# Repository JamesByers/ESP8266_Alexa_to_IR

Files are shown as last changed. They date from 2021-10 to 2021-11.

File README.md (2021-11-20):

# ESP8266 Alexa to IR controller
This repository demonstrates how to use an ESP8266 microcontroller to recieve Alexa commands and transmit corresponding IR commands. Specifically it demonstrates controlling a radiant heater that has no documentation of the IR signals sent. The code and technique can be leveraged for any IR device you want to control.

This repository assumes you know how to use the Arduino IDE and program an Arduino.  I used a [NodeMCU 1.0 ESP8266 development board](https://www.amazon.com/HiLetgo-Internet-Development-Wireless-Micropython/dp/B010O1G1ES) for this project. However this code can be used with other ESP8266 boards such as the [Adafruit HUZZAH ESP8266 Breakout](https://www.adafruit.com/product/2471) or [SparkFun ESP8266 Thing](https://www.sparkfun.com/products/13231).

##### The project described here controls a radiant heater which comes with an IR remote. This repository contains two code sections
1. [alexa_ir_controller](/alexa_ir_controller) (transmitter) - Circuit and code to use an ESP8266 to recieve Alexa commands and then issue the corresponding IR commands through an IR LED
2. [ir_receiver](/ir_receiver) - Code to detect the IR command signals sent from an IR remote using a IR reciever part

##### See the controller in use:

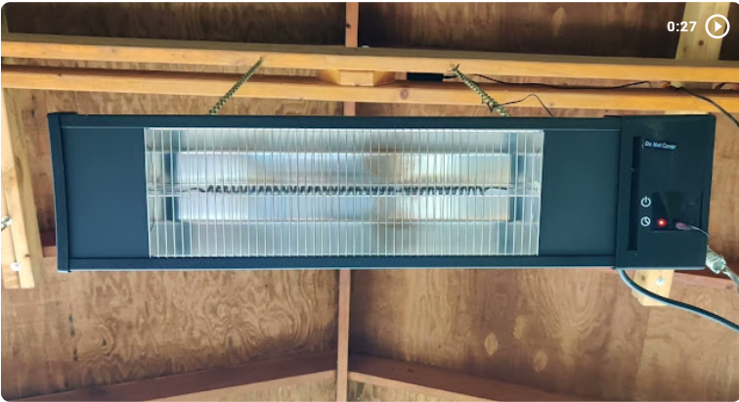
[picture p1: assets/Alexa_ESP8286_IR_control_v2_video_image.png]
The Alexa ESP8266 IR controller in action (27 sec) (https://photos.app.goo.gl/GmGifkKtMW2HBMPd7 "The Alexa ESP8266 IR controller in action (27 sec)")


##### Image of the completed controller

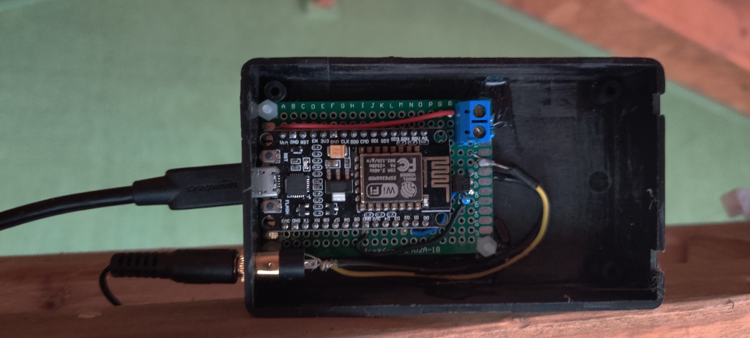
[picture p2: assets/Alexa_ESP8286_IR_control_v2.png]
Completed Alexa ESP8266 IR controller

Yeah, I know that looks like a cold solder joint but it is working reliably so I am leaving it as is.

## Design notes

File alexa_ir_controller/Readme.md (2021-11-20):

# ESP8266 Alexa to IR controller (transmitter)
This section of the repository demonstrates how to use an ESP8266 to recieve Alexa commands and transmit corresponding IR commands. Specifically it demonstrates controlling a radiant heater that has no documentation of the IR signals.  The NodeMCU Arduino code is available in the [code/alexa_ir_heater_controller](./code/alexa_ir_heater_controller/) folder.

### The IR codes
I obtained the IR codes by pushing each button on the remote and capturing it with the IR reciever set-up described in the [ir_receiver](../ir_receiver/) folder of this repository. The codes I captured can be seen in the [heater_remote_IR_codes](../ir_receiver/heater_remote_IR_codes_v2.txt) file in that folder.  In the Arduino NodeMCU code I used the hexidecimal representation of the IR tramsmissions.

### In order to make one of these you will need this hardware:
* [NodeMCU v1.0 ESP8266 development board](https://www.amazon.com/HiLetgo-Internet-Development-Wireless-Micropython/dp/B010O1G1ESS) or other ESP8266 development board such as the [Adafruit HUZZAH ESP8266 Breakout](https://www.adafruit.com/product/2471) or [SparkFun ESP8266 Thing](https://www.sparkfun.com/products/13231)
* Small signal transistor such as the 2N2222 or 555 IC to drive the LED
  * Demonstrating how to use a 555 timer IC instead of a small signal transistor is beyond the scope of this repository.  However to do so you use the 555 as shown in [this diagram](../assets/555_timer_as_buffer_to_drive_led.png).  The diagram shows a configuration that puts the 555 into buffer mode.  This is a subset of the Bistable Mode. You don't see it described much but it is a very viable use of a 555 IC. The buffer would be between NodeMCU pin and the LED in order to provide enough current to the LED without much load on the NodeMCU pin. Thus it provides the same function as the discrete transistor I show in the photos and breadboard image. There are other 555 diagrams in the [assets](../assets/) folder that may also be helpful.
* 220 Ohm and 470 Ohm resistors
 * Note that since the "Vin" pin on the ESP8266 outputs ~4.5v when the power is coming from the USB cord rather than 5v, the 220 Ohn resistor could instead be something like 200 Ohm instead abd be a bit brighter.  But I had 220 Ohm resistors on hand and with the 220 Ohm one the IR LED is bright enough for for my application.
* IR LED

### Alexa to IR tranmitter circuit:
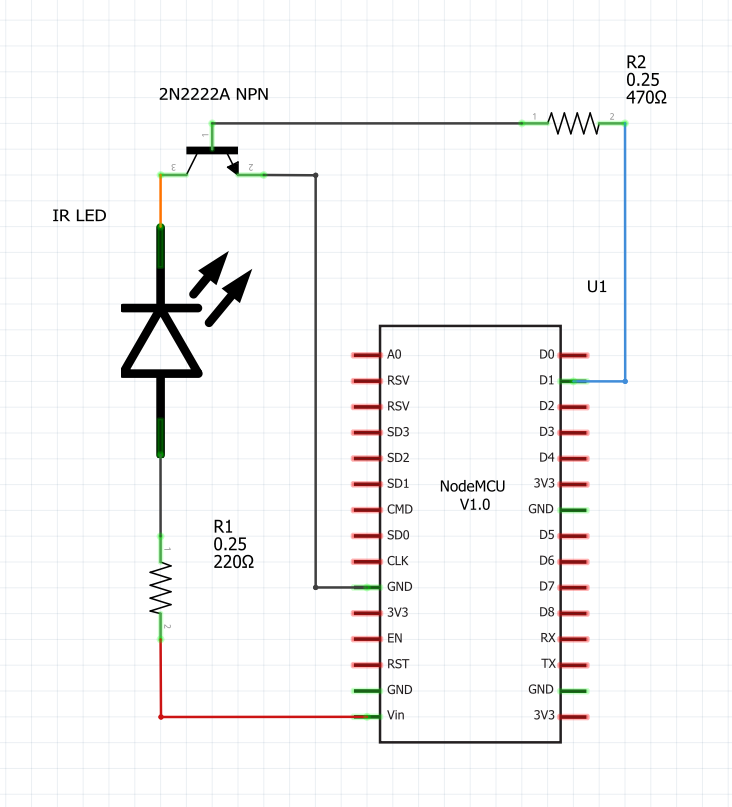
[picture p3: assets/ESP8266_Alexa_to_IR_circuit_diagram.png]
Circuit Diagram Alexa to IR circuit diagram


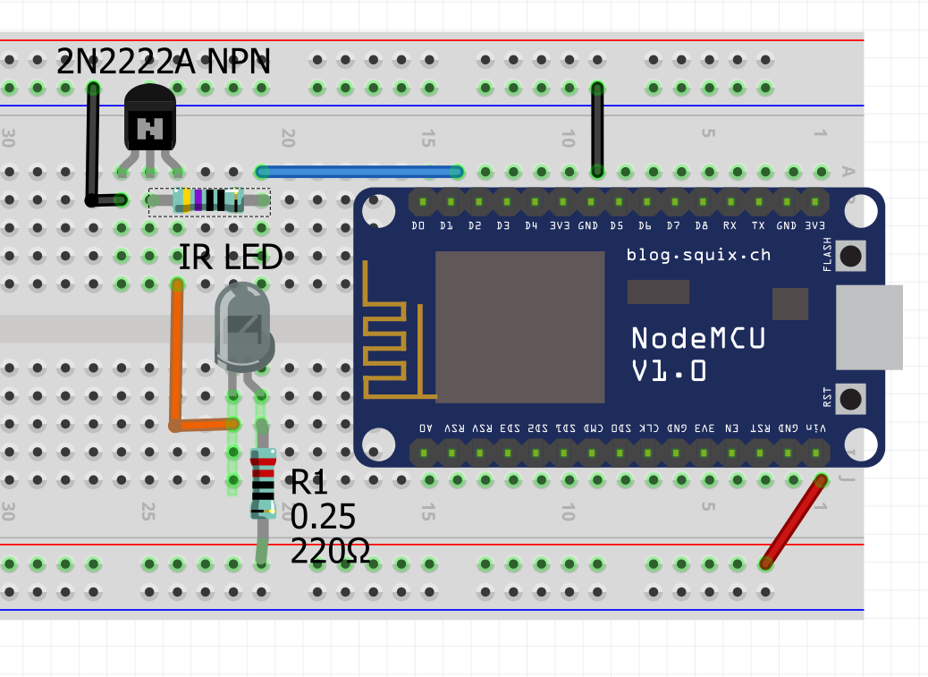
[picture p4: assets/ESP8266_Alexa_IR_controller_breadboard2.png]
Breadboard image ESP_Alexa_IR_controller_circuit

* Link to the [Fritzing file](../assets/ESP8266_Alexa_IR_controller_w_transistor_2.fzz) of the breadboard circuit

### In order to make one of these you will need to install these Arduino libraries
* fauxmoESP  2.4.3 This rev is the last rev that simulated a Wemo smart plug.  Later 3.x versions simulate a Philips lightbulb.  The code in this repo will not work with 3.x and latter since this code creates three simulated Wemo smart plugs.  Since they can recieve on On and Off commands from Alexa there are a total of six commands we can use.  I have tried adding a 4th Wemo device in the code for additional commands but it appears that Alexa limits the number of Wemo plugs from a single IP address to three.  An improved version of this code would use the newest version of the fauxmo library since it simulates a Philips light providing not only On and Off but 100 levels of brightness.  That would allow you to use 102 commands to the simulated device, a vast improvement.  But I jsut need six so the code in this repo is sufficient for my use.
  * If you are using a development board like the NodeMCU v1.0 that contains a ESP8266 you will need to also install the ESP8266WiFi library
  * If you are using a development board like the NodeMCU v0.9 that contains a ESP32 you will need to install the WIFI library instead 
* IRremoteESP8266.h
* IRsend.h

When the code is downloaded to the NodeMCU and run it will create three devices that can be discovered by Alexa
* Heater device 1
* Heater device 2
* Heater device 3

To use these devices after adding them through Alexa device discovery, create Alexa routines the use the three devices On/Off states to issue IR commands that can be recieved by the heater
* [Heater control - Alexa and resulting IR commands from the ESP8266](https://docs.google.com/spreadsheets/d/1thoHuIrcbselhGR-zq0jwYt2loby5acfT-mOes6eoRw/edit?usp=sharing) mapping
* [Alexa heater routines](https://1drv.ms/w/s!AkhQRfMv5GmDhSj3fwgvKryUF9b4?e=UReHWI) to make the controller do what you want with the 6 total device states

### See the controller in action:

The Alexa ESP8266 IR controller in action (27 sec) (https://photos.app.goo.gl/GmGifkKtMW2HBMPd7 "The Alexa ESP8266 IR controller in action (27 sec)")

### Image of the completed controller

Completed Alexa ESP8266 IR controller

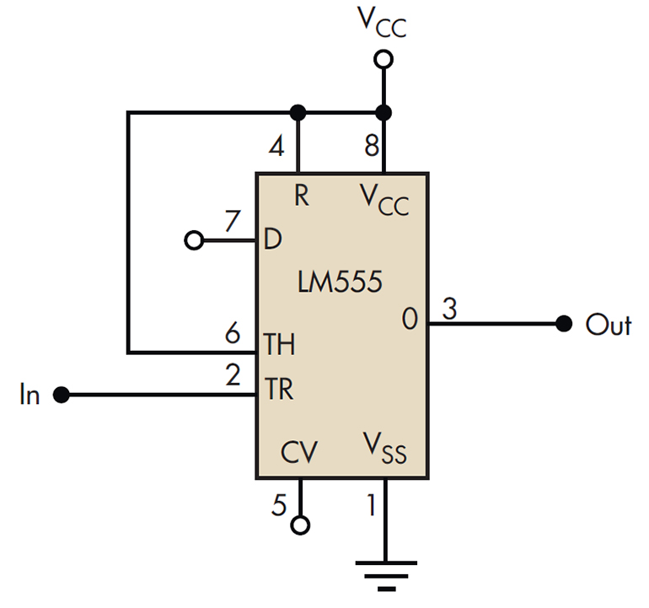
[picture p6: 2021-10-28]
assets/555_timer_ as_INVERTED_buffer_to_drive_led.png

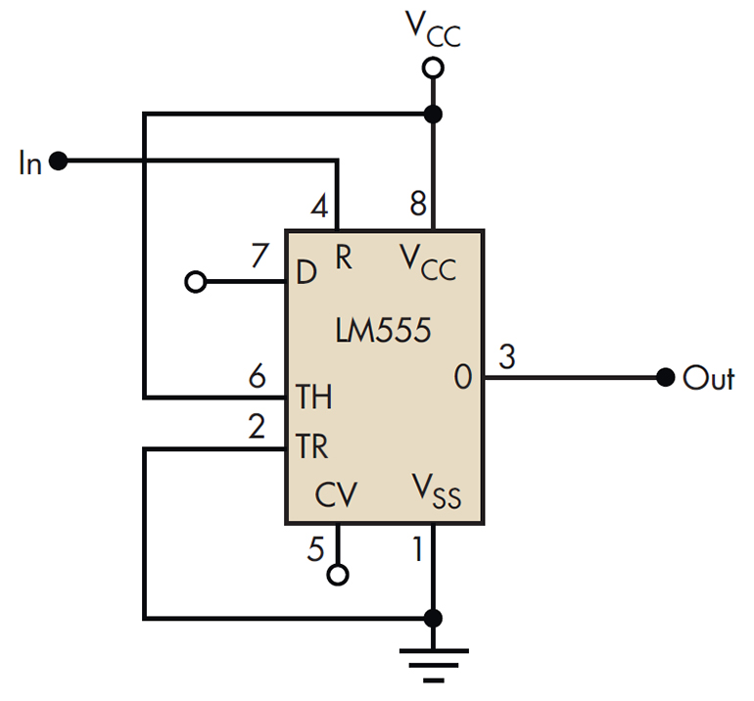
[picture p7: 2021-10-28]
assets/555_timer_as_buffer_to_drive_led.png

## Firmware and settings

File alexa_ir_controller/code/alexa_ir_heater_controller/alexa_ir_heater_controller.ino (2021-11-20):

// This code uses fauxmoESP version 2.4.3 to emulate a Wemo plug. It will need to be modified to use
// newer fauxmoESP libraries since fauxmoESP changed in Version 3 to emulating a Phillips light.
// the 3.0 version and later have the advanage that the 2.4.3 version could only add three devices
// to Alexa for a total of 6 unique commands per IP address.  THe newer implementation can provide 
// hundreds of cammands as it implements the dimming from 1-100 levels.  That is a great advantage.
// The code here will compile with the newer libraries but alas Alexa was unable to detect them. Therefore,
// this code should only be compliled with fauxmoESP 2.4.3.

#include <Arduino.h>
#ifdef ESP32
    #include <WiFi.h>
#else
    #include <ESP8266WiFi.h>
#endif
#include "fauxmoESP.h"
#include <IRremoteESP8266.h>
#include <IRsend.h>
#include "credentials.h"  // copy the credentials.sample.h file and add your 
                          // WIFI SSID and password to make a credentials.h file

#define SERIAL_BAUDRATE                 115200
#define LED                             4

fauxmoESP fauxmo;

unsigned int heat_on_off = 0xFFA25D;
unsigned int _500_watts  = 0xFFA857;
unsigned int _1000_watts = 0xFF18E7;
unsigned int _1500_watts = 0xFF4AB5;
unsigned int timer = 0xFFE817;
unsigned int heat_count = 3;

const uint16_t kIrLed = 4;  // ESP8266 GPIO pin to use. Recommended: 4 (D2).
IRsend irsend(kIrLed);  // Set the GPIO to be used to send the IR message.

// -----------------------------------------------------------------------------
// Wifi
// -----------------------------------------------------------------------------

void wifiSetup() {

    // Set WIFI module to STA mode
    WiFi.mode(WIFI_STA);

    // Connect
    Serial.printf("[WIFI] Connecting to %s ", WIFI_SSID);
    WiFi.begin(WIFI_SSID, WIFI_PASS);

    // Wait
    while (WiFi.status() != WL_CONNECTED) {
        Serial.print(".");
        delay(500);
    }
    Serial.println();

    // Connected!
    Serial.printf("[WIFI] STATION Mode, SSID: %s, IP address: %s\n", WiFi.SSID().c_str(), WiFi.localIP().toString().c_str());

}

void setup() {

    // Init serial port and clean garbage
    Serial.begin(SERIAL_BAUDRATE);
    Serial.println();
    Serial.println();

    // Wifi
    wifiSetup();

    // LED test
    // pinMode(LED, OUTPUT);
    // digitalWrite(LED, HIGH);

    // You have to call enable(true) once you have a WiFi connection
    // You can enable or disable the library at any moment
    // Disabling it will prevent the devices from being discovered and switched
    fauxmo.enable(true);

    fauxmo.addDevice("Heater device 1");
    fauxmo.addDevice("Heater device 2");
    fauxmo.addDevice("Heater device 3");

    // fauxmoESP 2.0.0 has changed the callback signature to add the device_id,
    // this way it's easier to match devices to action without having to compare strings.

    // Callback to retrieve current state (for GetBinaryState queries)
    fauxmo.onGetState([](unsigned char device_id, const char * device_name) {
        return !digitalRead(LED);
    });

    fauxmo.onSetState([](unsigned char device_id, const char * device_name, bool state) {
        // Logic for transmitting IR commands when Alexa command is to Heater device 1    
        if (strcmp(device_name, "Heater device 1") == 0) {
          Serial.println("");
          Serial.print("Heater Device 1:");
          Serial.print(state);
          Serial.println("");
          if (state) {
            Serial.println("Heater init");
            irsend.sendNEC(heat_on_off);
            delay(1000);
            Serial.println("1000 watts");
            irsend.sendNEC(_1000_watts);
            delay(1000);
            Serial.println("Timer On with 1 hr");
            irsend.sendNEC(timer);  // Send first to trigger heater to await timer command
            delay(1000);
            irsend.sendNEC(timer);  // Send again to trigger heater to add one hr to the timer
              
            //delay(300);   // Uncomment to test LED by leaving it on 
            //digitalWrite(LED, HIGH);   // Uncomment to test LED by leaving it on
              
            }
          else {
            Serial.println("Heater Off");
            irsend.sendNEC(heat_on_off);
            //delay(300);
            //digitalWrite(LED, LOW); //LED Test
            }
          }
    
        // Logic for transmitting IR commands when Alexa command is to Heater device 2
        if (strcmp(device_name, "Heater device 2") == 0) {
          Serial.println("");
          Serial.print("Heater Device 2:");
          Serial.print(state);
          Serial.println("");
          if (state) {
            Serial.println("500 watts");
            irsend.sendNEC(_500_watts);      
            }
          else {
            Serial.println("1000 watts");
            irsend.sendNEC(_1000_watts);  
            }
          }
    
        // Logic for transmitting IR commands when Alexa command is to Heater device 3
        if (strcmp(device_name, "Heater device 3") == 0) {
          Serial.println("");
          Serial.print("Heater device 3:");
          Serial.print(state);
          Serial.println("");
          if (state) {
            Serial.println("1500 watts");
            irsend.sendNEC(_1500_watts);      
            }
          else {
            irsend.sendNEC(timer);
            delay(1000);
            irsend.sendNEC(timer);  // Send again to trigger heater to add one hr to the timer
            }
          }
    });    

}

void loop() {

    // Since fauxmoESP 2.x the library uses the "compatibility" mode by
    // default, this means that it uses WiFiUdp class instead of AsyncUDP.
    // The later requires the Arduino Core for ESP8266 staging version
    // whilst the former works fine with current stable 2.3.0 version.
    // But, since it's not "async" anymore we have to manually poll for UDP
    // packets
    
    fauxmo.handle();

    static unsigned long last = millis();
    if (millis() - last > 5000) {
        last = millis();
        Serial.printf("[MAIN] Free heap: %d bytes\n", ESP.getFreeHeap());
    }

}

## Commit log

2021-11-19 Added schematic
2021-11-19 fixed the resistor values in the breadbord image
2021-11-19 fixed the resistor values in the schematic
2021-11-20 added colored wires to the schematic
